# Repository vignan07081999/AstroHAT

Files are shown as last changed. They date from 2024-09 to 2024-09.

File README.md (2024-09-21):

### AstroHAT
## Raspberry Pi HAT for Astrophotography

This project is centered around developing a custom Raspberry Pi HAT designed to enhance astrophotography setups. It aims to streamline power management, integrate essential functionalities, and provide a platform for further expansion.

**Astrophotography**

Astrophotography is a specialized field of photography that captures celestial objects and phenomena. This often involves long exposure times, precise tracking, and specialized equipment.

**Stellarmate OS**

Stellarmate OS is a Linux distribution tailored for astrophotography. It provides a user-friendly interface and integrates with various astronomy software and hardware.

**ASCOM and INDI Protocols**

ASCOM and INDI are communication protocols widely used in astrophotography to facilitate interaction between different devices and software. ASCOM is primarily used on Windows, while INDI is platform-independent.

**Project Overview**

This custom Raspberry Pi HAT is currently under development with the following features and goals:

* **Power Management:**  Provides a centralized power solution for the Raspberry Pi and connected astrophotography devices. 
* **EEPROM:**  Includes an EEPROM for storing configuration data and other persistent information.
* **Real-Time Clock (RTC):**  Features a built-in RTC to ensure accurate timekeeping, even without an internet connection.

**Future Plans**

The project roadmap includes:

* **GPS Integration:**  Adding GPS functionality to enable precise location and time tracking.
* **Reduced Footprint:**  Optimizing the design to minimize the HAT's size and weight.
* **External USB Support:**  Including support for connecting additional USB devices.

**Current Status**

The project is actively in progress. The core functionalities of power management, EEPROM, and RTC are being developed and tested.

**Contributions**

Contributions, suggestions, and feedback are welcome! Please feel free to open issues or submit pull requests. 

**License**

This project is not yet licensed

**Disclaimer**

This project is experimental and may undergo significant changes. Use at your own risk.

**Let's make astrophotography more accessible and enjoyable!**

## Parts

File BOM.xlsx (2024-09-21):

Page | Reference Field | ComponentName | Part name/number | Seller/Manufacturer | Value if any | Link
Root | J1 | 40 Pin Out | 40 Pin GPIO Connector Header | PiShop |  | https://www.pishop.ca/product/40-pin-gpio-connector-header/
Root | J2 | DC Barrel Jack | 474-PRT-10811 | Mouser |  | https://www.mouser.ca/ProductDetail/SparkFun/PRT-10811?qs=WyAARYrbSna7U1x2Qa%2FYmw%3D%3D
Root | J3 | DC Barrel Jack | 474-PRT-10811 | Mouser |  | https://www.mouser.ca/ProductDetail/SparkFun/PRT-10811?qs=WyAARYrbSna7U1x2Qa%2FYmw%3D%3D
Root | J4 | DC Barrel Jack | 474-PRT-10811 | Mouser |  | https://www.mouser.ca/ProductDetail/SparkFun/PRT-10811?qs=WyAARYrbSna7U1x2Qa%2FYmw%3D%3D
Root | J5 | DC Barrel Jack | 474-PRT-10811 | Mouser |  | https://www.mouser.ca/ProductDetail/SparkFun/PRT-10811?qs=WyAARYrbSna7U1x2Qa%2FYmw%3D%3D
EEPROM | U1 | EEPROM | 571-1205911 | Mouser | EEPROM 256kb I2C Serial CMOS EEPROM | https://www.mouser.ca/ProductDetail/onsemi/CAT24C256WI-GT3?qs=rZgeL6XvLwaEqwp5Dppodg%3D%3D
HAT protection | Q1 | MOSFET | 581-06033A103JAT2A | Mouser | MOSFETs P-Ch ENH FET -20V 52mOh -5A | https://www.mouser.ca/ProductDetail/Diodes-Incorporated/DMG2305UX-13?qs=L1DZKBg7t5Hgw5KN3G2IRg%3D%3D
HAT protection | Q2A | Bipolar Transistors - BJT | 581-AHA0608150M050R | Mouser | Bipolar Transistors - BJT MATCHED PNP SM SIGNAL TRANS | https://www.mouser.ca/ProductDetail/Diodes-Incorporated/DMMT5401-7-F?qs=hiZRsJxw0h3f7LzTPwvEFQ%3D%3D
HAT protection | Q2B | Bipolar Transistors - BJT | 581-AHA0608150M050R | Mouser | Bipolar Transistors - BJT MATCHED PNP SM SIGNAL TRANS | https://www.mouser.ca/ProductDetail/Diodes-Incorporated/DMMT5401-7-F?qs=hiZRsJxw0h3f7LzTPwvEFQ%3D%3D
HAT protection | R1 | Resistor | 581-AHA0608150M050R | Mouser | 10K OHM | https://www.mouser.ca/ProductDetail/Vishay-Dale/CRCW020110K0FNED?qs=IQLUlsvFoXuh7T4rhkKYcQ%3D%3D
HAT protection | R2 | Resistor | 581-KAF21KR72A474KU | Mouser | 47K OHM | https://www.mouser.ca/ProductDetail/Vishay-Dale/CRCW020147K0FKED?qs=NYScm%2FwlDDZcrvbe%2FhKd4A%3D%3D
24v to 5v | U2 | Switching Voltage Regulators | 581-KAM15AR71H103MT | Mouser | HIGH EFF 5A STEP- DOWN VLTG REG | https://www.mouser.ca/ProductDetail/Texas-Instruments/LM2678S-ADJ-NOPB?qs=X1J7HmVL2ZH7NNbF47L5nQ%3D%3D
24v to 5v | C1 | Aluminum Electrolytic Capacitors | 581-KAM15AR71H103MT | Mouser | SMD 15UF 50V ESR=80 | https://www.mouser.ca/ProductDetail/KYOCERA-AVX/AHA0608150M050R?qs=Wj%2FVkw3K%252BMB6LS5S%2FtUOGw%3D%3D
24v to 5v | C2 | Aluminum Electrolytic Capacitors | 621-DMG2305UX-13 | Mouser | SMD 15UF 50V ESR=81 | https://www.mouser.ca/ProductDetail/KYOCERA-AVX/AHA0608150M050R?qs=Wj%2FVkw3K%252BMB6LS5S%2FtUOGw%3D%3D
24v to 5v | C3 | Aluminum Electrolytic Capacitors | 621-DMMT5401-7-F | Mouser | SMD 15UF 50V ESR=82 | https://www.mouser.ca/ProductDetail/KYOCERA-AVX/AHA0608150M050R?qs=Wj%2FVkw3K%252BMB6LS5S%2FtUOGw%3D%3D
24v to 5v | C4 | Multilayer Ceramic Capacitors MLCC | 621-DMMT5401-7-F | Mouser | SMD/SMT 100V .47uF X7R 0805 10% AEC-Q200 FLEXITE | https://www.mouser.ca/ProductDetail/KYOCERA-AVX/KAF21KR72A474KU?qs=Jm2GQyTW%2FbjffqBFDb40cQ%3D%3D
24v to 5v | C5 | Multilayer Ceramic Capacitors MLCC | 652-SRP1770TA-680M | Mouser | SMD/SMT .01UF 25V 5% 0603 | https://www.mouser.ca/ProductDetail/KYOCERA-AVX/06033A103JAT2A
24v to 5v | C6 | Tantalum Capacitors | 652-SRP1770TA-680M | Mouser | Solid SMD 180uF 16volts 10% R case Conformal | https://www.mouser.ca/ProductDetail/Vishay-Sprague/595D187X9016R2T?qs=yTmH%252B1d%252BRGOGgdhzT2pmnA%3D%3D
24v to 5v | C7 | Tantalum Capacitors | 667-EEE-FK1V151GV | Mouser | Solid SMD 180uF 16volts 10% R case Conformal | https://www.mouser.ca/ProductDetail/Vishay-Sprague/595D187X9016R2T?qs=yTmH%252B1d%252BRGOGgdhzT2pmnA%3D%3D
24v to 5v | L1 | Power Inductors | 667-EEE-FK1V151GV | Mouser | SMD WE-MAPI 22uH 600mA DCR=1.04Ohms AEC-Q200 | https://www.mouser.ca/ProductDetail/Wurth-Elektronik/74438335220?qs=ZB8tH5z5N7bAy7niI35oLA%3D%3D
24v to 5v | BR1 | Schottky Diode | 667-ERA-8APB103V | Mouser | 45V 6A IF Single TO-220AC | https://www.mouser.ca/ProductDetail/Vishay-Semiconductors/VS-6TQ045STRL-M3?qs=3SS1MhAOHqqGctID3FUnfw%3D%3D
24v to 12v | U3 | Switching Voltage Regulators | 667-ERA-8APB103V | Mouser | 150 KHZ 3A STEP-DOWN VLTG REG | https://www.mouser.ca/ProductDetail/Texas-Instruments/LM2596S-12-NOPB?qs=X1J7HmVL2ZF8LB%2FmfveaIg%3D%3D
24v to 12v | C8 | Aluminum Organic Polymer Capacitors | 698-CAT24C256WI-GT3 | Mouser | 25Vol 180uF SMD 2KHr ESR=29 mOhms | https://www.mouser.ca/ProductDetail/KEMET/A768KE187M1ELAE029?qs=vmHwEFxEFR%2FDt2gz0sjJJw%3D%3D
24v to 12v | C9 | Aluminum Electrolytic Capacitors | 700-DS3231M+ | Mouser | SMD 35VDC 150uF 20% Anti-Vibe AEC-Q200 | https://www.mouser.ca/ProductDetail/Panasonic/EEE-FK1V151GV?qs=PzGy0jfpSMsRRaqaGHaOYQ%3D%3D
24v to 12v | L2 | Power Inductors | 710-74438335220 | Mouser | SMD 68uH 20% | https://www.mouser.ca/ProductDetail/Bourns/SRP1770TA-680M?qs=ZwKJWZfDtNh5geHyuqA3%2FQ%3D%3D
24v to 12v | D2 | Schottky Diodes & Rectifiers | 71-CRCW0201-10K | Mouser | 2A, 60V, Schottky Rectifier | https://www.mouser.ca/ProductDetail/Taiwan-Semiconductor/SS26?qs=JV7lzlMm3yKinAezXtOeEg%3D%3D
24v to 12v_2 | U4 | Switching Voltage Regulators | 71-CRCW020147K0FKED | Mouser | 150 KHZ 3A STEP-DOWN VLTG REG | https://www.mouser.ca/ProductDetail/Texas-Instruments/LM2596S-12-NOPB?qs=X1J7HmVL2ZF8LB%2FmfveaIg%3D%3D
24v to 12v_2 | C10 | Aluminum Organic Polymer Capacitors | 74-595D187X9016R2T | Mouser | 25Vol 180uF SMD 2KHr ESR=29 mOhms | https://www.mouser.ca/ProductDetail/KEMET/A768KE187M1ELAE029?qs=vmHwEFxEFR%2FDt2gz0sjJJw%3D%3D
24v to 12v_2 | C11 | Aluminum Electrolytic Capacitors | 74-595D187X9016R2T | Mouser | SMD 35VDC 150uF 20% Anti-Vibe AEC-Q200 | https://www.mouser.ca/ProductDetail/Panasonic/EEE-FK1V151GV?qs=PzGy0jfpSMsRRaqaGHaOYQ%3D%3D
24v to 12v_2 | L3 | Power Inductors | 78-VS-6TQ045STRL-M3 | Mouser | SMD 68uH 20% | https://www.mouser.ca/ProductDetail/Bourns/SRP1770TA-680M?qs=ZwKJWZfDtNh5geHyuqA3%2FQ%3D%3D
24v to 12v_2 | D2 | Schottky Diodes & Rectifiers | 80-A768KE187M1ELAE29 | Mouser | 2A, 60V, Schottky Rectifier | https://www.mouser.ca/ProductDetail/Taiwan-Semiconductor/SS26?qs=JV7lzlMm3yKinAezXtOeEg%3D%3D
RTC | U5 | Real Time Clock | 80-A768KE187M1ELAE29 | Mouser | 5ppm, I2C Real-Time Clock | https://www.mouser.ca/ProductDetail/Analog-Devices-Maxim-Integrated/DS3231M%2b?qs=Bakm8ERcljpd4MQpcnSykw%3D%3D
RTC | R3 | Thin Film Resistors | 821-SS26 | Mouser | SMD 10K OHM .1% 15PPM 1/4W | https://www.mouser.ca/ProductDetail/Panasonic/ERA-8APB103V?qs=PgLP5AltfoxbwGsvBPb74A%3D%3D
RTC | R4 | Thin Film Resistors | 821-SS26 | Mouser | SMD 10K OHM .1% 15PPM 1/4W | https://www.mouser.ca/ProductDetail/Panasonic/ERA-8APB103V?qs=PgLP5AltfoxbwGsvBPb74A%3D%3D
RTC | C12 | Multilayer Ceramic Capacitors MLCC | 926-LM2596S-12/NOPB | Mouser | SMD/SMT 50V 10 000pF X7R 060 3 20% AEC-Q200 | https://www.mouser.ca/ProductDetail/KYOCERA-AVX/KAM15AR71H103MT?qs=Jm2GQyTW%2FbgIjfHDdYgdPA%3D%3D
RTC | C13 | Multilayer Ceramic Capacitors MLCC | 926-LM2596S-12/NOPB | Mouser | SMD/SMT 50V 10 000pF X7R 060 3 20% AEC-Q200 | https://www.mouser.ca/ProductDetail/KYOCERA-AVX/KAM15AR71H103MT?qs=Jm2GQyTW%2FbgIjfHDdYgdPA%3D%3D
RTC | BT1 | Coin Cell Battery Holders | 926-LM2678S-ADJ/NOPB | Mouser | 1P COIN CELL HRZ T-H BATT HOLDR | https://www.mouser.ca/ProductDetail/TE-Connectivity/120591-1?qs=cB%252BprIo57OeZ1n1mnEiYEw%3D%3D

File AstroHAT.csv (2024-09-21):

Id | Designator | Footprint | Quantity | Designation | Supplier and ref
1 | U3,U4 | TO-263-5_TabPin3 | 2 | LM2596S-12
2 | U2 | TO127P1435X464-8N | 1 | LM2678T-5.0
3 | R1 | R_0201_0603Metric | 1 | 10k ohm
4 | D2,D1 | D_SMA | 2 | SS26
5 | L1 | L_Wuerth_MAPI-4020 | 1 | 22uH
6 | C1,C2,C3 | CAPAE660X850N | 3 | 15uF/50V
7 | C13,C5,C12 | C_0201_0603Metric | 3 | 0.01uF
8 | R4 | R_2512_6332Metric | 1 | 10K Ohm
9 | C11,C8 | CAPAE830X700N | 2 | 180uF/25V
10 | R2 | R_0201_0603Metric | 1 | 47k ohm
11 | Q2 | SOT-23-6 | 1 | DMMT5401
12 | C4 | CAPC3216X152N | 1 | 0.47uF
13 | BT1 | 120591-1 | 1 | 120591-1
14 | C9,C10 | EEHZA1H680P | 2 | 150uF/35V
15 | U1 | SOIC127P600X175-8N | 1 | CAT24C256
16 | U5 | SOIC-16W_7.5x10.3mm_P1.27mm | 1 | DS3231M
17 | R3 | R_2512_6332Metric | 1 | 10K ohm
18 | Q1 | SOT91P240X110-3N | 1 | DMG2305UX-13
19 | C7 | CAPPC5958X380N | 1 | 180uF/16V
20 | L2,L3 | PA4344683NLT | 2 | 68uH
21 | J2 | BarrelJack_CUI_PJ-102AH_Horizontal | 1 | 24Vin
22 | J1 | PinSocket_2x20_P2.54mm_Vertical | 1 | Raspberry Pi Pinout
23 | J3 | BarrelJack_CUI_PJ-102AH_Horizontal | 1 | 5Vout
24 | J5,J4 | BarrelJack_CUI_PJ-102AH_Horizontal | 2 | Jack-DC
25 | BR1 | VS6TQ045STRLM3 | 1 | VS-6TQ045-M3
26 | C6 | CAPPC5958X380N | 1 | 180uF/16v

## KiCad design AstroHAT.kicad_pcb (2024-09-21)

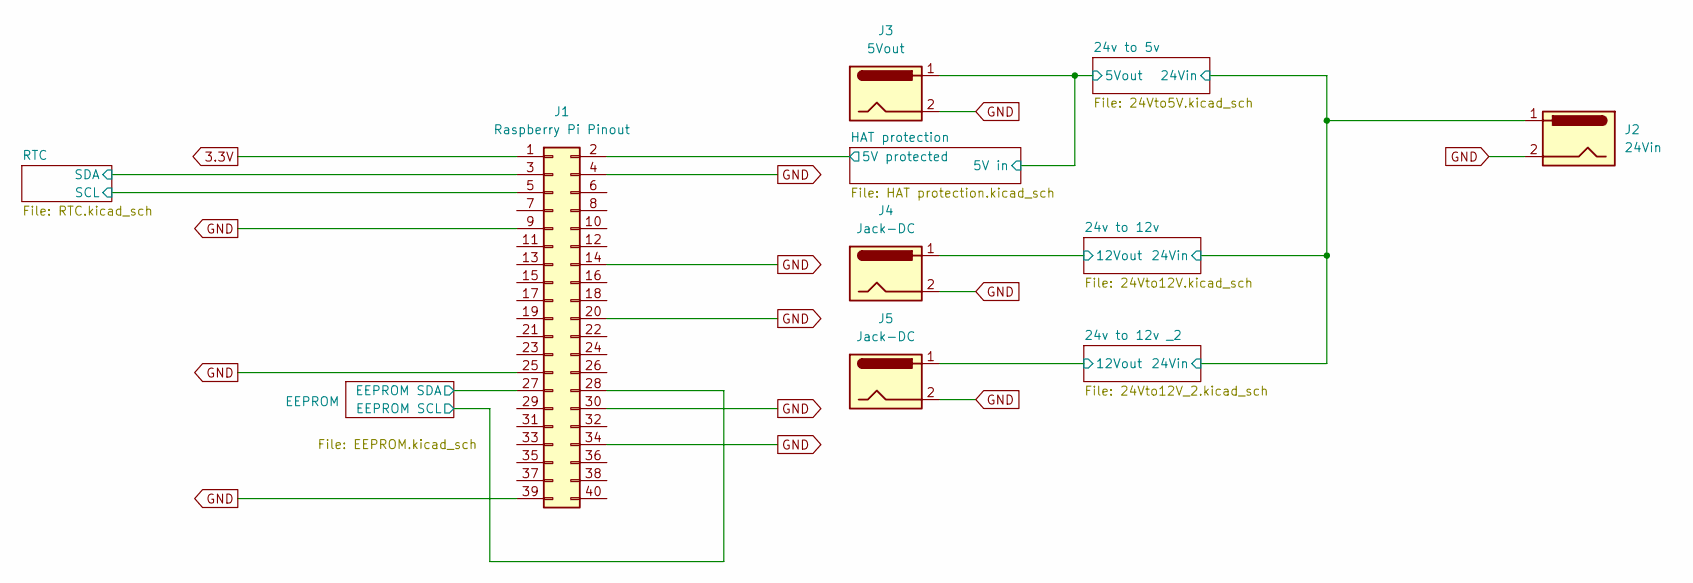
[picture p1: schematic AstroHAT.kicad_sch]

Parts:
J1: Raspberry Pi Pinout; PinSocket_2x20_P2.54mm_Vertical
J2: 24Vin; BarrelJack_CUI_PJ-102AH_Horizontal
J3: 5Vout; BarrelJack_CUI_PJ-102AH_Horizontal
J4, J5: Jack-DC; BarrelJack_CUI_PJ-102AH_Horizontal

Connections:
3.3V: J1.1; also elsewhere on the board
/24v to 5v/5Vout: J3.1; also elsewhere on the board
/24v to 12v _2/12Vout: J5.1; also elsewhere on the board
/24v to 12v _2/24Vin: J2.1; also elsewhere on the board
/24v to 12v/12Vout: J4.1; also elsewhere on the board
/EEPROM/EEPROM SCL: J1.28; also elsewhere on the board
/EEPROM/EEPROM SDA: J1.27; also elsewhere on the board
/HAT protection/5V protected: J1.2; also elsewhere on the board
/RTC/SCL: J1.5; also elsewhere on the board
/RTC/SDA: J1.3; also elsewhere on the board
GND: J1.4, J1.9, J1.14, J1.20, J1.25, J1.30, J1.34, J1.39, J2.2, J3.2, J4.2, J5.2; also elsewhere on the board

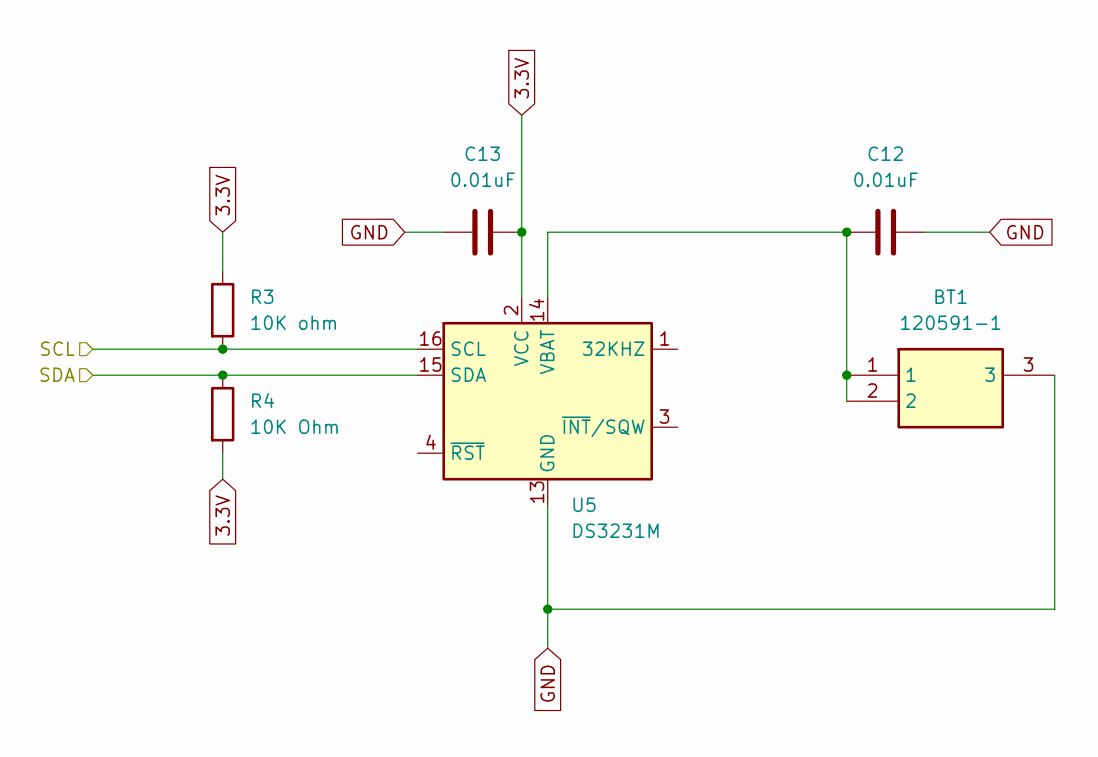
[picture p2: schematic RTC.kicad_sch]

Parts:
BT1: 120591-1; Mouser Part Number 571-1205911
C12, C13: 0.01uF; C_0201_0603Metric
R3: 10K ohm; R_2512_6332Metric
R4: 10K Ohm; R_2512_6332Metric
U5: DS3231M; SOIC-16W_7.5x10.3mm_P1.27mm

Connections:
3.3V: C13.2, R3.1, R4.2, U5.2 (VCC); also elsewhere on the board
/RTC/SCL: R3.2, U5.16 (SCL); also elsewhere on the board
/RTC/SDA: R4.1, U5.15 (SDA); also elsewhere on the board
GND: BT1.3, C12.2, C13.1, U5.5 (GND), U5.6 (GND), U5.7 (GND), U5.8 (GND), U5.9 (GND), U5.10 (GND), U5.11 (GND), U5.12 (GND), U5.13 (GND); also elsewhere on the board
unnamed: BT1.1, BT1.2, C12.1, U5.14 (VBAT)

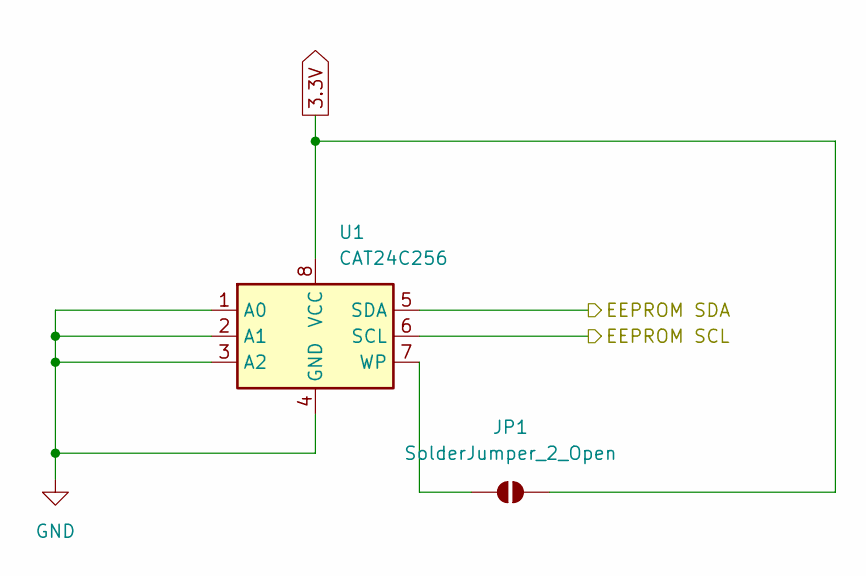
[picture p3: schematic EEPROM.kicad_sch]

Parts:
JP1: SolderJumper_2_Open; SolderJumper-2_P1.3mm_Open_RoundedPad1.0x1.5mm
U1: CAT24C256; SOIC127P600X175-8N

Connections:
3.3V: JP1.2 (B), U1.8 (VCC); also elsewhere on the board
/EEPROM/EEPROM SCL: U1.6 (SCL); also elsewhere on the board
/EEPROM/EEPROM SDA: U1.5 (SDA); also elsewhere on the board
GND: U1.1 (A0), U1.2 (A1), U1.3 (A2), U1.4 (GND); also elsewhere on the board
unnamed: JP1.1 (A), U1.7 (WP)

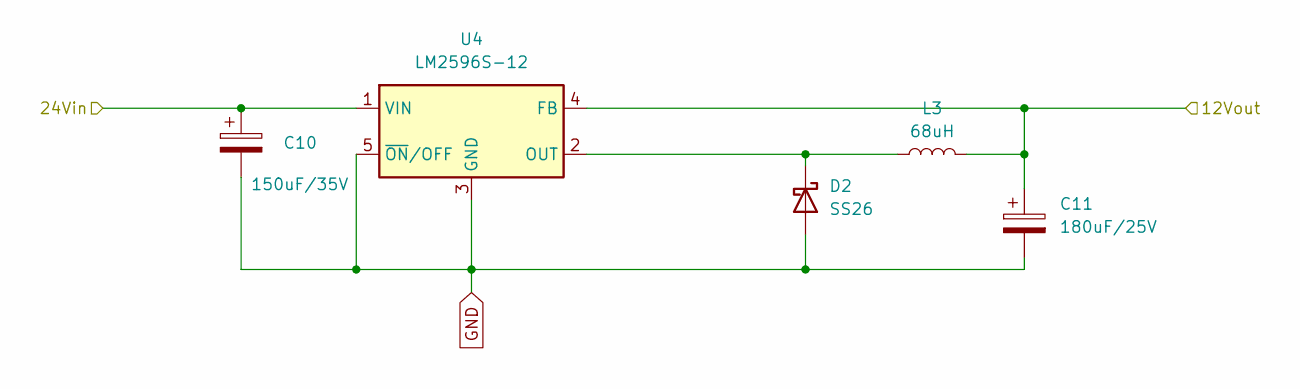
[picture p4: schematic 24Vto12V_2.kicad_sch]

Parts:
C10: 150uF/35V; EEHZA1H680P
C11: 180uF/25V; CAPAE830X700N
D2: SS26; D_SMA
L3: 68uH; PA4344683NLT
U4: LM2596S-12; TO-263-5_TabPin3

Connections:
/24v to 12v _2/12Vout: C11.1, L3.2, U4.4 (FB); also elsewhere on the board
/24v to 12v _2/24Vin: C10.1, U4.1 (VIN); also elsewhere on the board
GND: C10.2, C11.2, D2.2 (A), U4.3 (GND), U4.5 (~ON/OFF); also elsewhere on the board
unnamed: D2.1 (K), L3.1, U4.2 (OUT)

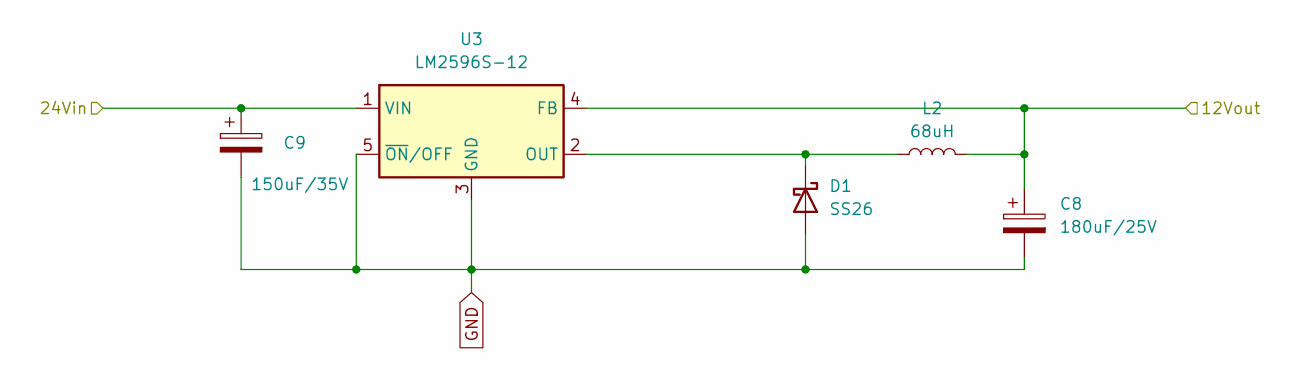
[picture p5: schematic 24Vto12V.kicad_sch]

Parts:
C8: 180uF/25V; CAPAE830X700N
C9: 150uF/35V; EEHZA1H680P
D1: SS26; D_SMA
L2: 68uH; PA4344683NLT
U3: LM2596S-12; TO-263-5_TabPin3

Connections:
/24v to 12v _2/24Vin: C9.1, U3.1 (VIN); also elsewhere on the board
/24v to 12v/12Vout: C8.1, L2.2, U3.4 (FB); also elsewhere on the board
GND: C8.2, C9.2, D1.2 (A), U3.3 (GND), U3.5 (~ON/OFF); also elsewhere on the board
unnamed: D1.1 (K), L2.1, U3.2 (OUT)

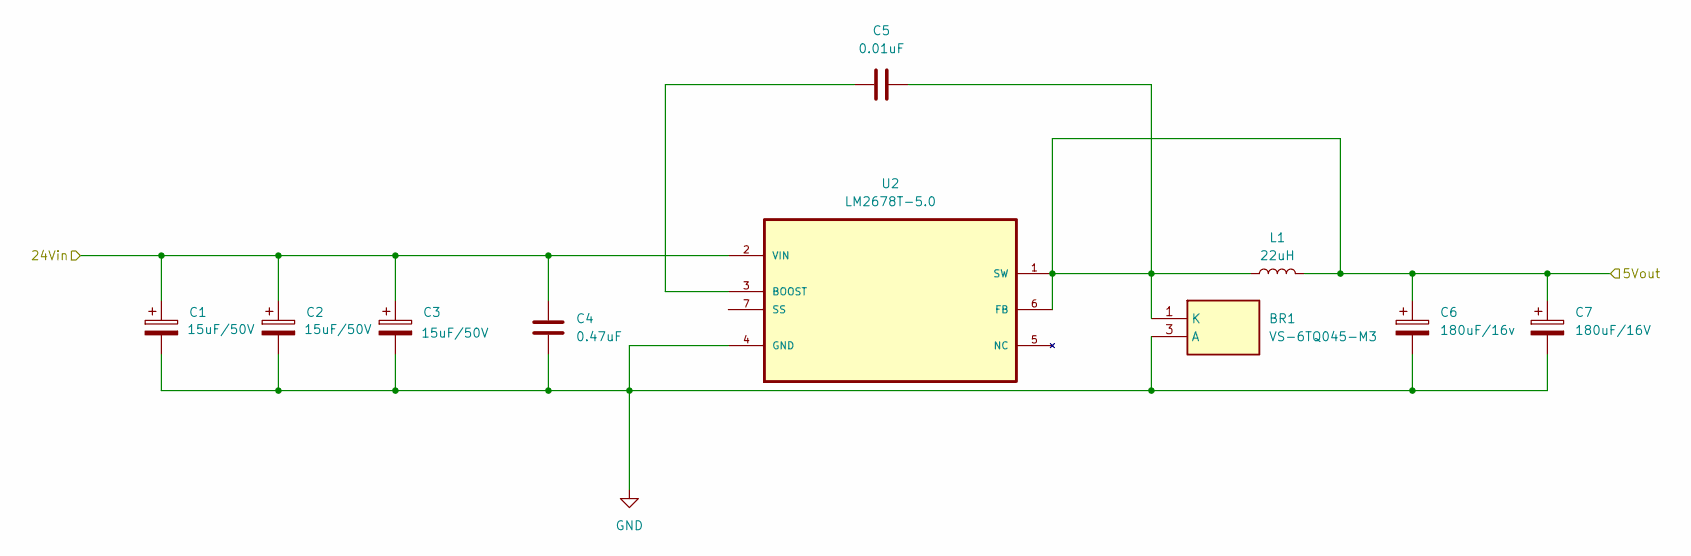
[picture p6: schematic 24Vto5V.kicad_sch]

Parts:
BR1: VS-6TQ045-M3; VS6TQ045STRLM3; Mouser Part Number 78-VS-6TQ045-M3
C1, C2, C3: 15uF/50V; CAPAE660X850N
C4: 0.47uF; CAPC3216X152N
C5: 0.01uF; C_0201_0603Metric
C6: 180uF/16v; CAPPC5958X380N
C7: 180uF/16V; CAPPC5958X380N
L1: 22uH; L_Wuerth_MAPI-4020
U2: LM2678T-5.0; TO127P1435X464-8N; MPN LLM2678T-5.0

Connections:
/24v to 5v/5Vout: BR1.1 (K), C5.1, C6.1, C7.1, L1.1, L1.2, U2.1 (SW), U2.6 (FB); also elsewhere on the board
/24v to 12v _2/24Vin: C1.1, C2.1, C3.1, C4.1, U2.2 (VIN); also elsewhere on the board
GND: BR1.3 (A), C1.2, C2.2, C3.2, C4.2, C6.2, C7.2, U2.4 (GND); also elsewhere on the board
unnamed: C5.2, U2.3 (BOOST)

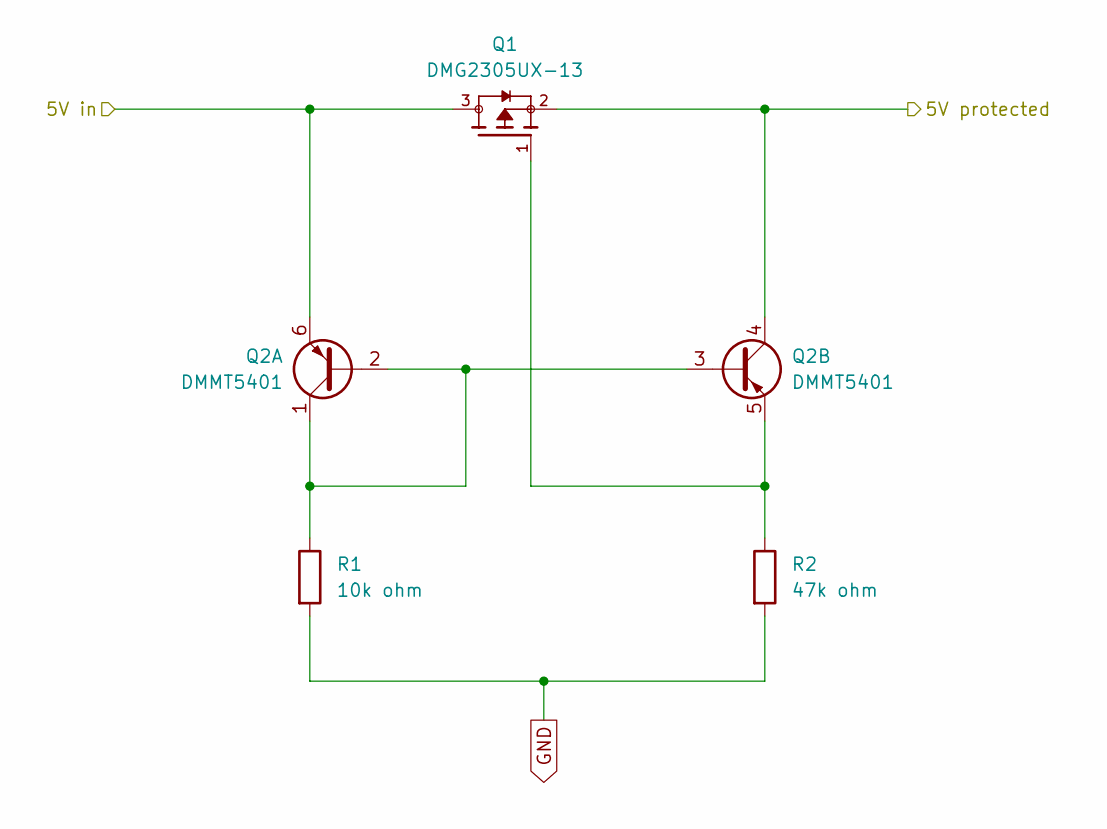
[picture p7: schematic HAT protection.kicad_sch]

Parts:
Q1: DMG2305UX-13; SOT91P240X110-3N; PARTREV 09/2018
Q2: DMMT5401; SOT-23-6
R1: 10k ohm; R_0201_0603Metric
R2: 47k ohm; R_0201_0603Metric

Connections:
/24v to 5v/5Vout: Q1.3, Q2.6 (E1); also elsewhere on the board
/HAT protection/5V protected: Q1.2, Q2.4 (C2); also elsewhere on the board
GND: R1.2, R2.2; also elsewhere on the board
unnamed: Q2.1 (C1), Q2.2 (B1), Q2.3 (B2), R1.1
unnamed: Q1.1, Q2.5 (E2), R2.1

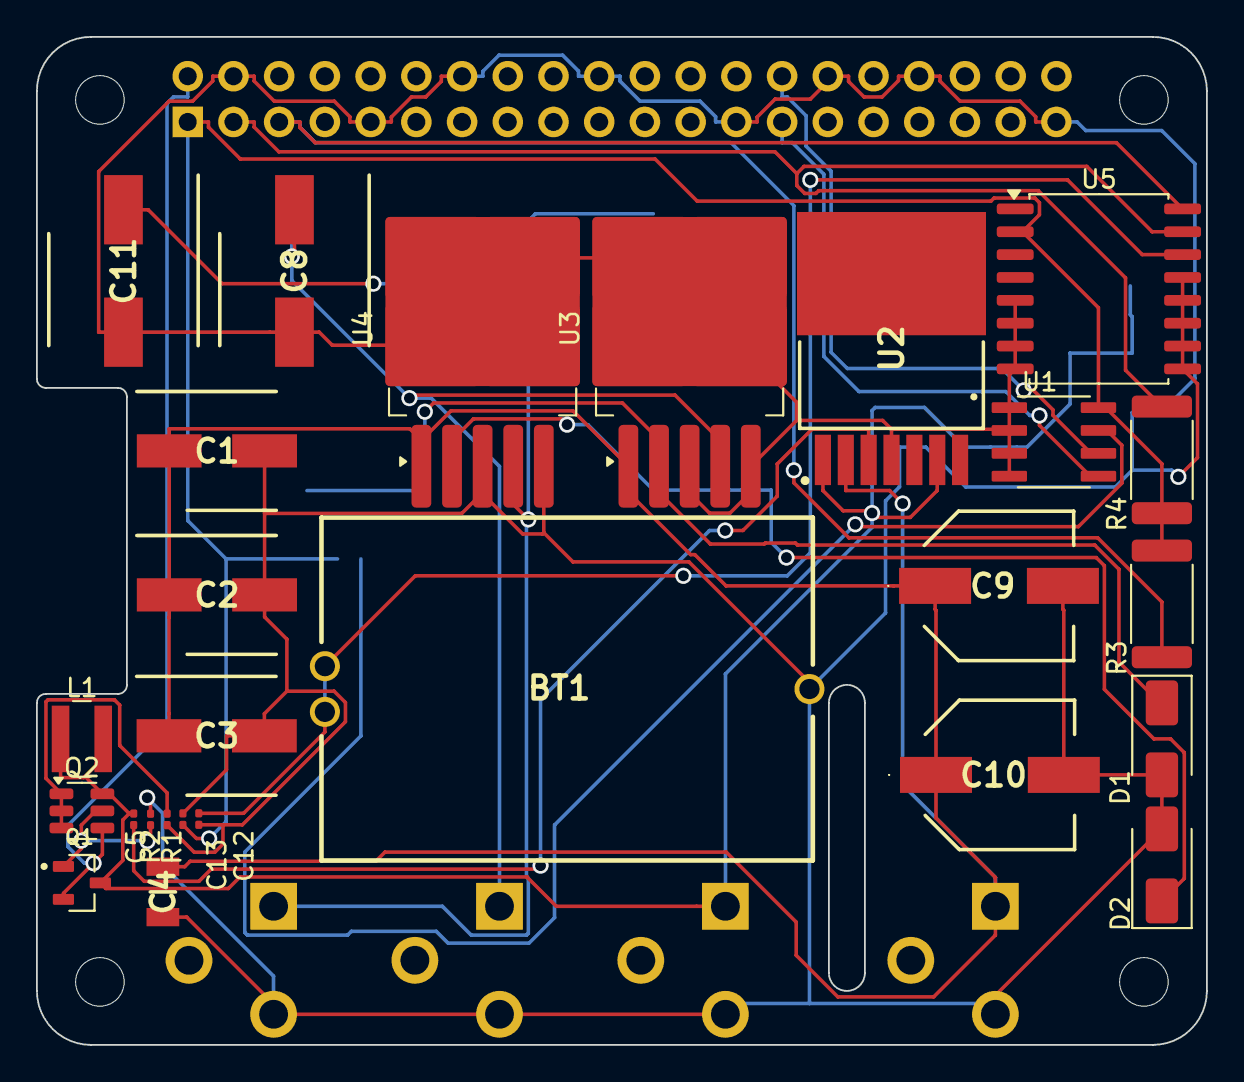
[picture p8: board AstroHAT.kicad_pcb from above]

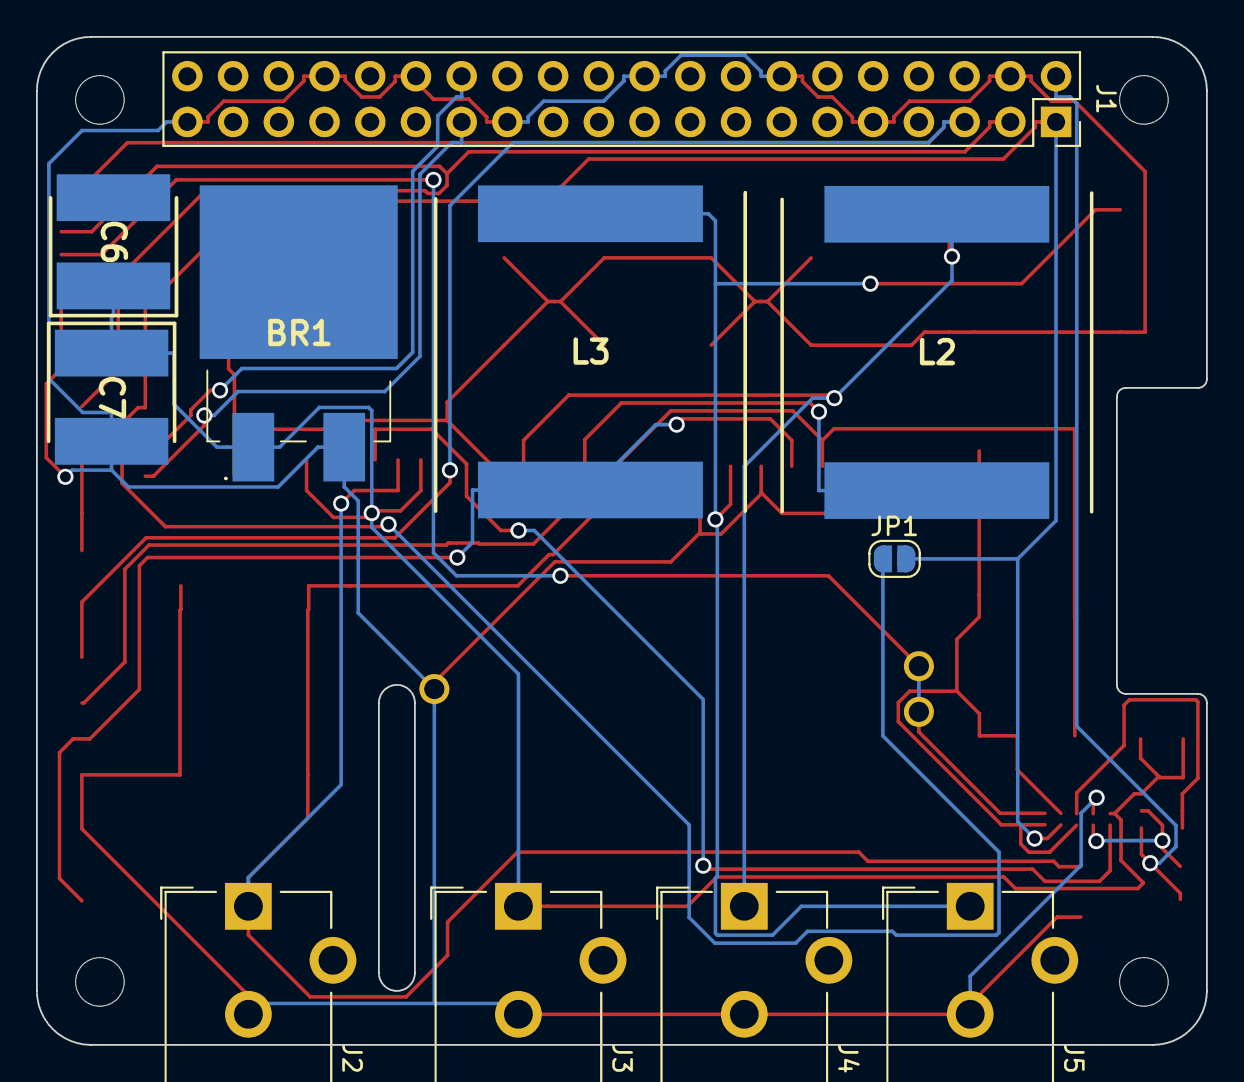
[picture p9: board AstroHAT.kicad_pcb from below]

Board: 2 copper layers, 65.0 x 56.0 mm, 41 parts (11 on the bottom side), 18 nets.

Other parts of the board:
MH1, MH2, MH3, MH4: MountingHole_2.7mm_M2.5
